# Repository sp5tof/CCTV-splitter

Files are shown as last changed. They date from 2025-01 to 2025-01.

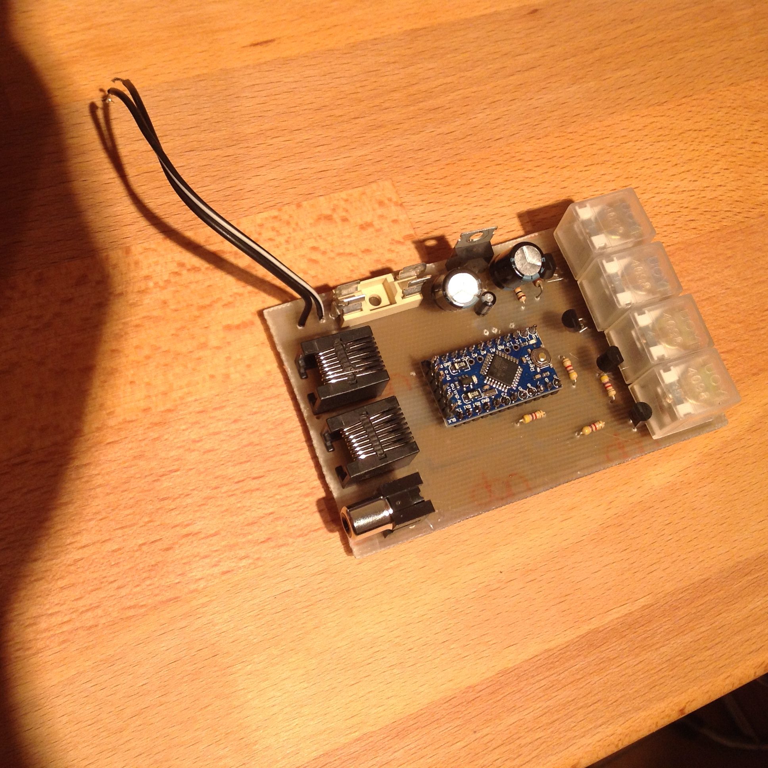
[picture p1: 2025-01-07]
zdjecie_Video_splitter-rotated.jpg

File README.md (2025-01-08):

This project is about switching the composite signals come from 4 CCTV cameras into one video receiver. Switching is done by remote IR controller (f.ex. TV remote controller).
Four IR codes have to be preconfigured within the arduino code.



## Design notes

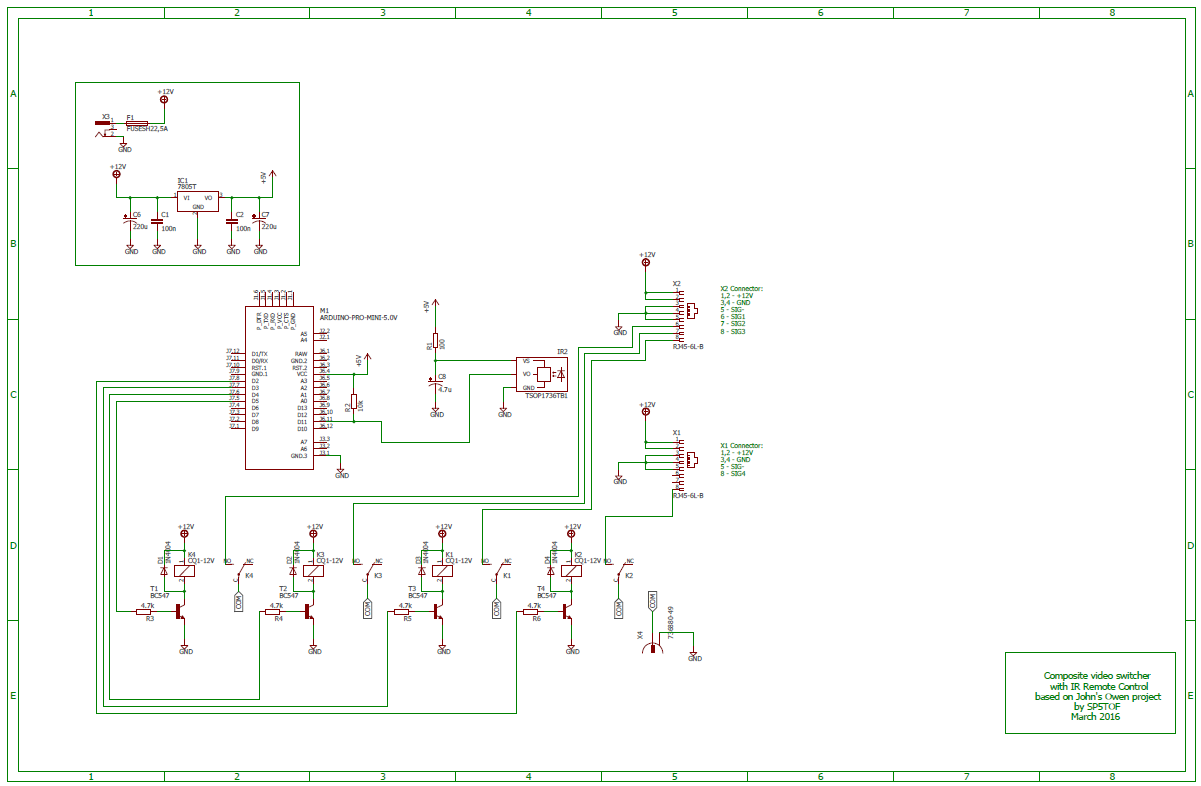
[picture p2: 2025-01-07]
video_splitter.png

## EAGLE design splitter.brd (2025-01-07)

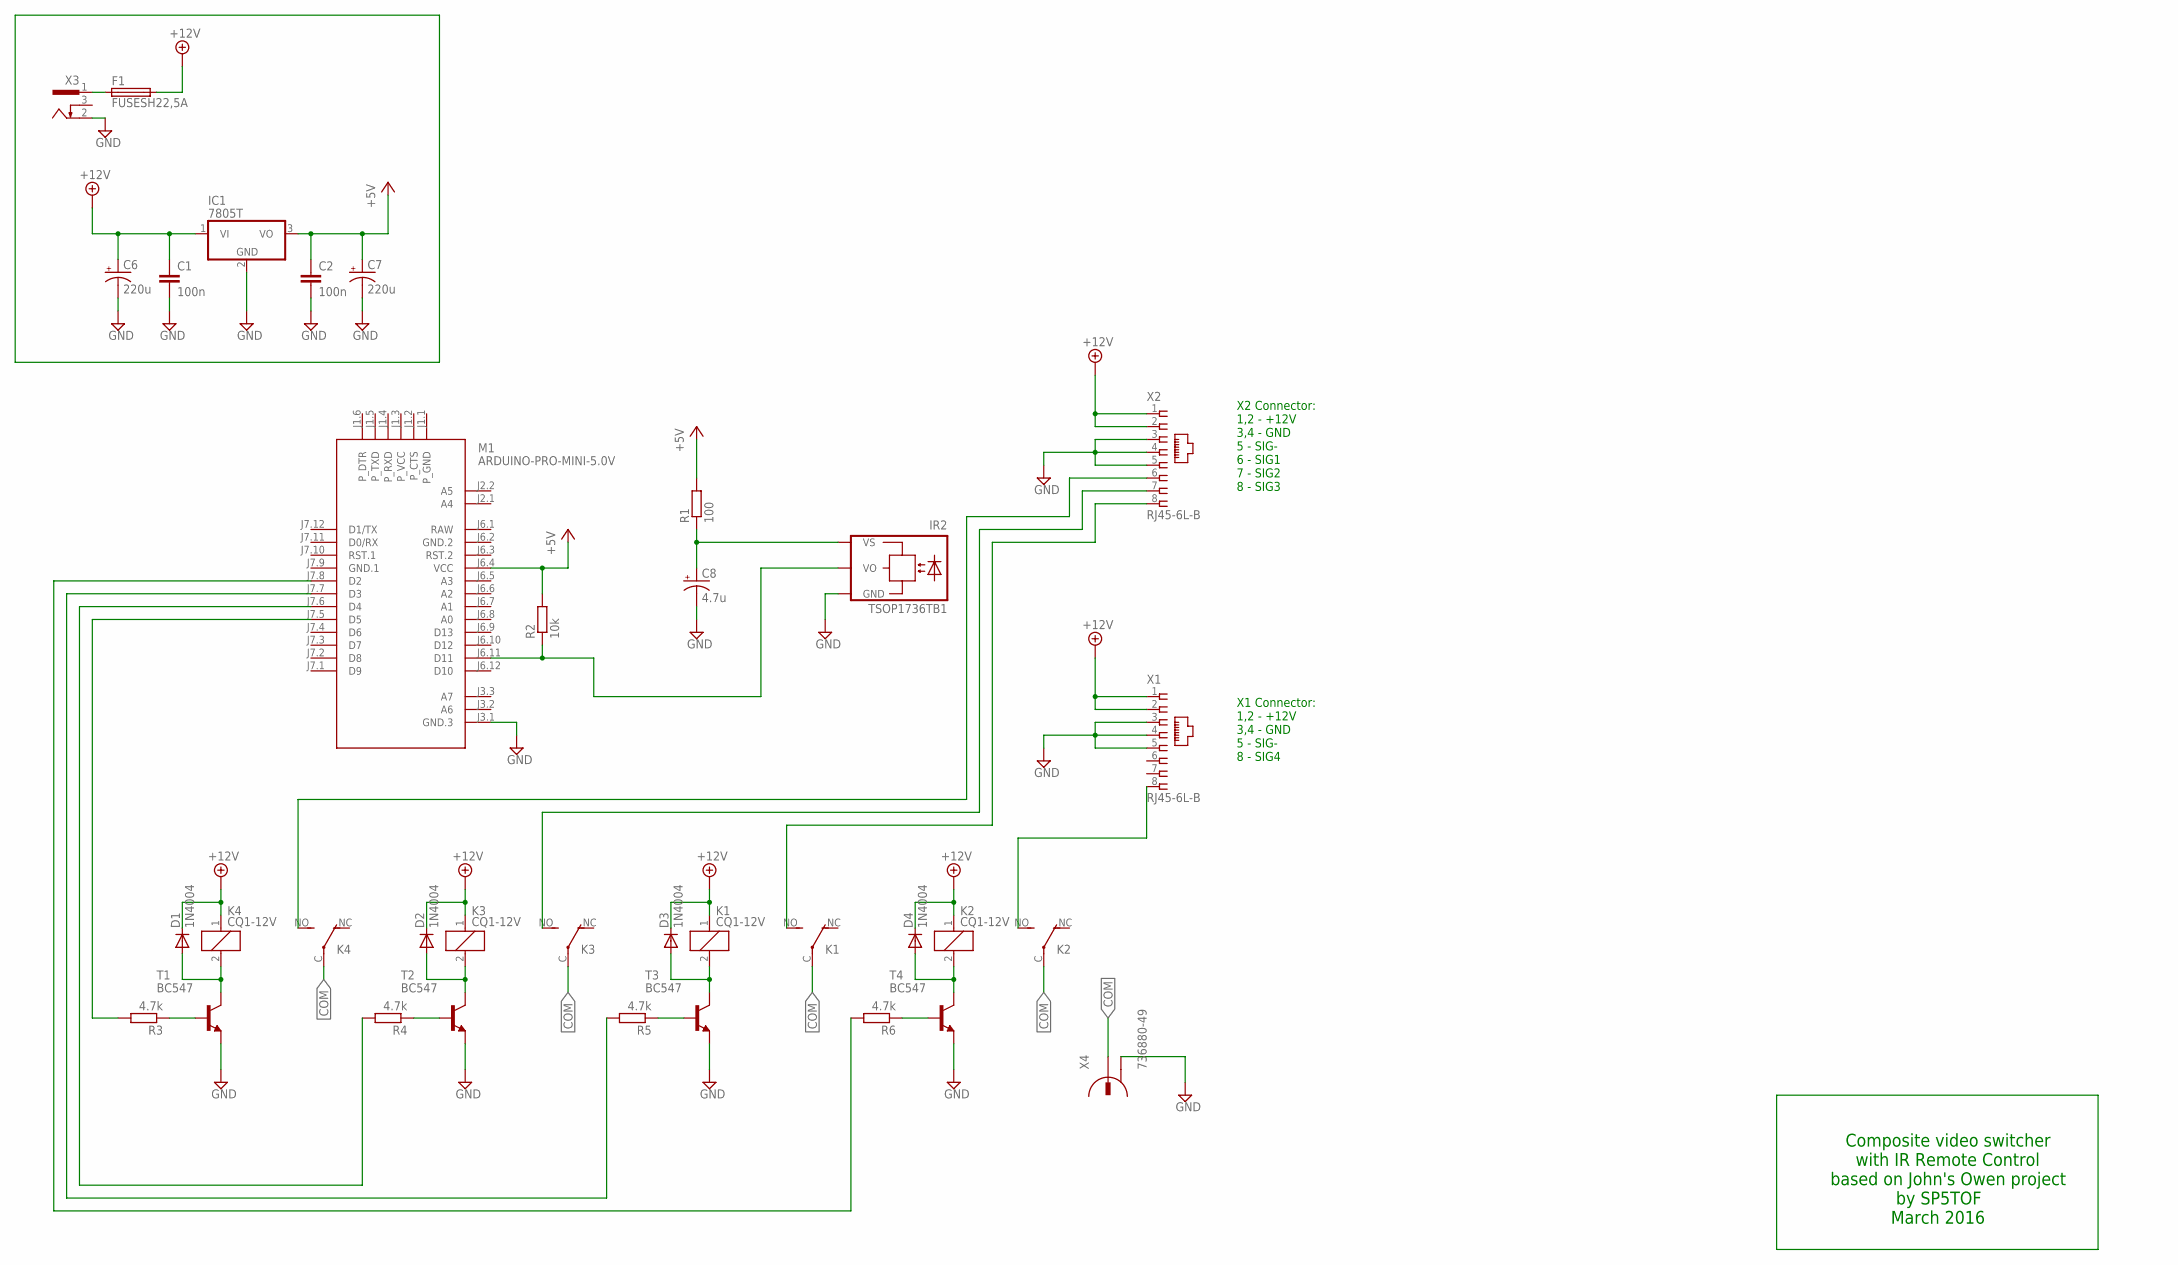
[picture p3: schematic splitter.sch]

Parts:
C1, C2: 100n; C025-024X044
C6, C7: 220u; CPOL-RADIAL-10UF-25V
C8: 4.7u; CPOL-RADIAL-10UF-25V
D1, D2, D3, D4: 1N4004; DO41-10
F1: FUSESH22,5A; SH22,5A
IC1: 7805T; TO220H
IR2: TSOP1736TB1; TSOP17_TB1
K1, K2, K3, K4: CQ1-12V; CQ1
M1: ARDUINO-PRO-MINI-5.0V; ARDUINO-PRO-MINI
R1: 100; 0204/7
R2: 10k; 0204/7
R3, R4, R5, R6: 4.7k; 0204/7
T1, T2, T3, T4: BC547; TO92
X1, X2: RJ45-6L-B; RJ45-NO-SHIELD
X3: 733980-62
X4: 736880-49

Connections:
+5V: C2.1, C7.1 (+), IC1.3 (VO), M1.J6.4 (VCC), R1.2, R2.2
+12V: C1.1, C6.1 (+), D1.C, D2.C, D3.C, D4.C, F1.2, IC1.1 (VI), K1.1, K2.1, K3.1, K4.1, X1.1, X1.2, X2.1, X2.2
COM: K1.C, K2.C, K3.C, K4.C, X4.1
GND: C1.2, C2.2, C6.2 (-), C7.2 (-), C8.2 (-), IC1.2 (GND), IR2.GND, M1.J3.1 (GND.3), T1.1 (E), T2.1 (E), T3.1 (E), T4.1 (E), X1.3, X1.4, X1.5, X2.3, X2.4, X2.5, X3.2, X4.2
GND.1: M1.J7.9 (GND.1)
GND.2: M1.J6.2 (GND.2)
unnamed: C8.1 (+), IR2.VS, R1.1
unnamed: F1.1, X3.1
unnamed: IR2.VO, M1.J6.11 (D11), R2.1
unnamed: R3.1, T1.2 (B)
unnamed: R4.1, T2.2 (B)
unnamed: R5.1, T3.2 (B)
unnamed: R6.1, T4.2 (B)
unnamed: D1.A, K4.2, T1.3 (C)
unnamed: M1.J7.7 (D3), R5.2
unnamed: M1.J7.6 (D4), R4.2
unnamed: D2.A, K3.2, T2.3 (C)
unnamed: D3.A, K1.2, T3.3 (C)
unnamed: D4.A, K2.2, T4.3 (C)
unnamed: K4.NO (S), X2.6
unnamed: K3.NO (S), X2.7
unnamed: K1.NO (S), X2.8
unnamed: K2.NO (S), X1.8
unnamed: M1.J7.5 (D5), R3.2
unnamed: M1.J7.8 (D2), R6.2
RAW: M1.J6.1 (RAW)

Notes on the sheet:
X2 Connector: 1,2 - +12V 3,4 - GND 5 - SIG- 6 - SIG1 7 - SIG2 8 - SIG3
X1 Connector: 1,2 - +12V 3,4 - GND 5 - SIG- 8 - SIG4
Composite video switcher with IR Remote Control based on John's Owen project by SP5TOF March 2016

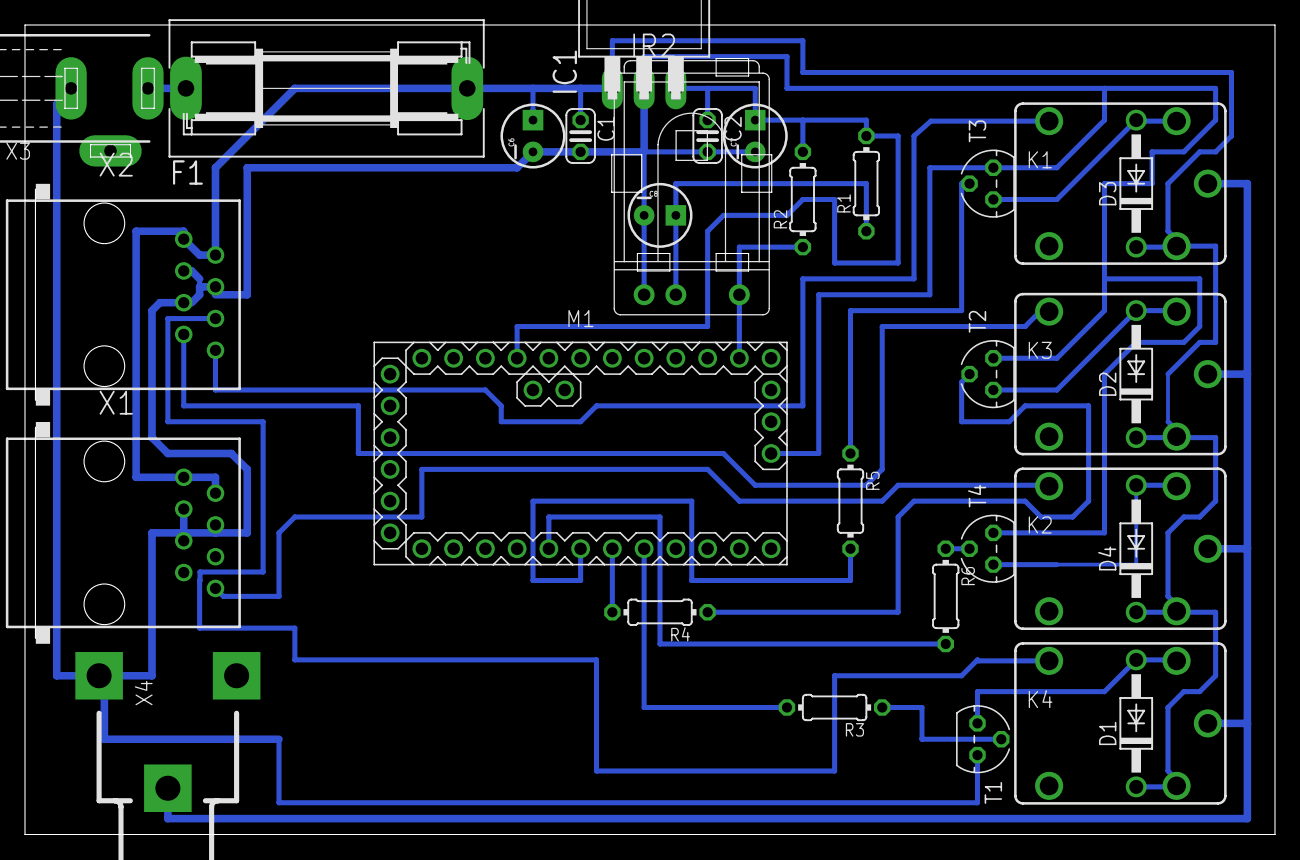
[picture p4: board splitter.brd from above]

Board: 2 copper layers, 100.0 x 64.8 mm, 31 parts (0 on the bottom side), 23 nets.

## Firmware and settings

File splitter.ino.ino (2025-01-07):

#include <IRremote.h>
#define irPin 11
IRrecv irrecv(irPin);
decode_results results;
 
#define sig1 5
#define sig2 4
#define sig3 3
#define sig4 2
unsigned long stan = 0 ;
unsigned long previousMillis = 0;
unsigned long interval = (unsigned long) 1000 * 60 * 60 ;

 
void setup() {
   Serial.begin(9600);
    irrecv.enableIRIn();
 
 for(int i=2;i<6;i++)
  {
    pinMode(i, OUTPUT);
    digitalWrite(i, LOW);
  }
}
 
void loop() {
  unsigned long currentMillis = millis();
  
   if (irrecv.decode(&results)) {
     
      switch (results.value) {
         case 0xE0E036C9: 
         if(stan!=results.value) 
         {
           wylacz_all();
           stan=results.value;
         
              
            digitalWrite(sig1, HIGH);
            delay(250);

            delay(1000);
         }
            break;
            
            case 0xE0E028D7:
         if(stan!=results.value)
         { 
           wylacz_all();
           stan=results.value;
              
            digitalWrite(sig2, HIGH);
            delay(250);
            
            delay(1000);}
            break;
            
             case 0xE0E0A857:
        if(stan!=results.value)
        {
          wylacz_all();
          stan=results.value;
              
            digitalWrite(sig3, HIGH);
            delay(250);
            
            delay(1000);}
            break;
            
             case 0xE0E06897:
        if(stan!=results.value) 
        {
          wylacz_all();
          stan=results.value;
              
            digitalWrite(sig4, HIGH);
            delay(250);
            
            delay(1000);}
            break;
            
         }
 
   irrecv.resume();
   }
     if (currentMillis - previousMillis > interval) {
    previousMillis = currentMillis;
      asm volatile ("  jmp 0");
  }
}

void wylacz_all()
{
                for(int i=2;i<6;i++)
              {
              digitalWrite(i, LOW);
              }
              delay(300);
}

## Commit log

2025-01-07 Add files via upload
    Photo of the circuit.
2025-01-07 Add files via upload
    Arduino code
2025-01-07 Add files via upload
    Eagle board project
    [splitter.brd]
2025-01-07 Add files via upload
    Eagle schema
    [splitter.sch]

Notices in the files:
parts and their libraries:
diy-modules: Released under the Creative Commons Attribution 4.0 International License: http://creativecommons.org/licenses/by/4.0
